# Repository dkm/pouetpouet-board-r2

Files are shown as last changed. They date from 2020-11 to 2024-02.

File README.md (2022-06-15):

# PouetPouet

The firmware is [Keyberon](https://github.com/TeXitoi/keyberon), a
pure rust firmware.

The goal was:
* build a custom keyboard from scratch
* continue to learn embedded rust
* have fun

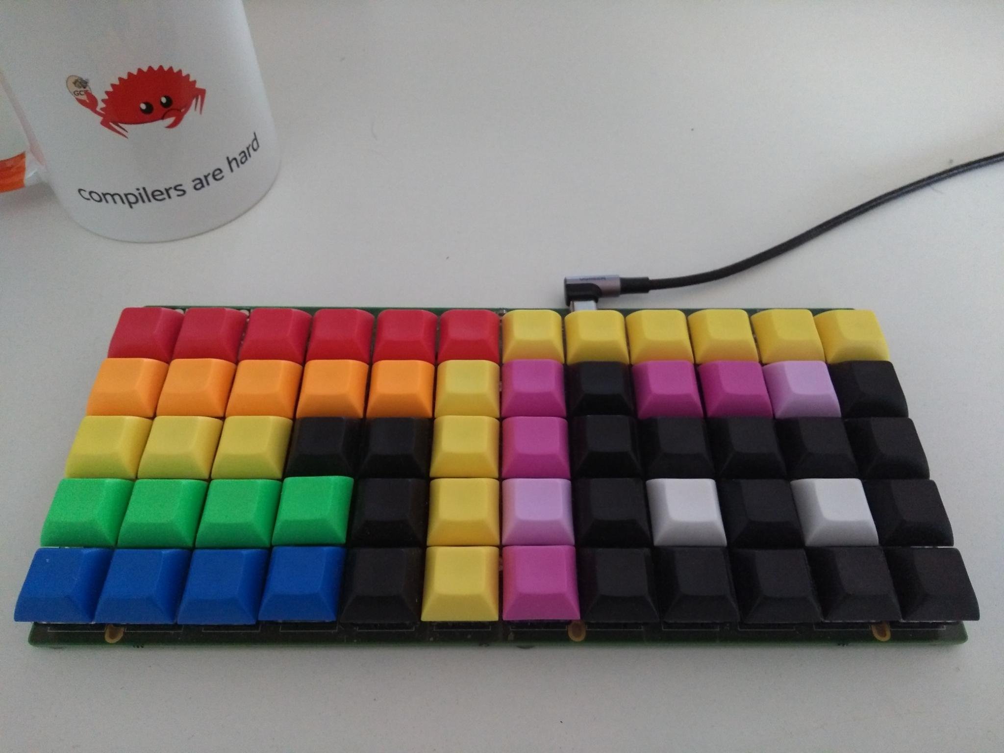
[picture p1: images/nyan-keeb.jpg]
PouetPouet Nyan

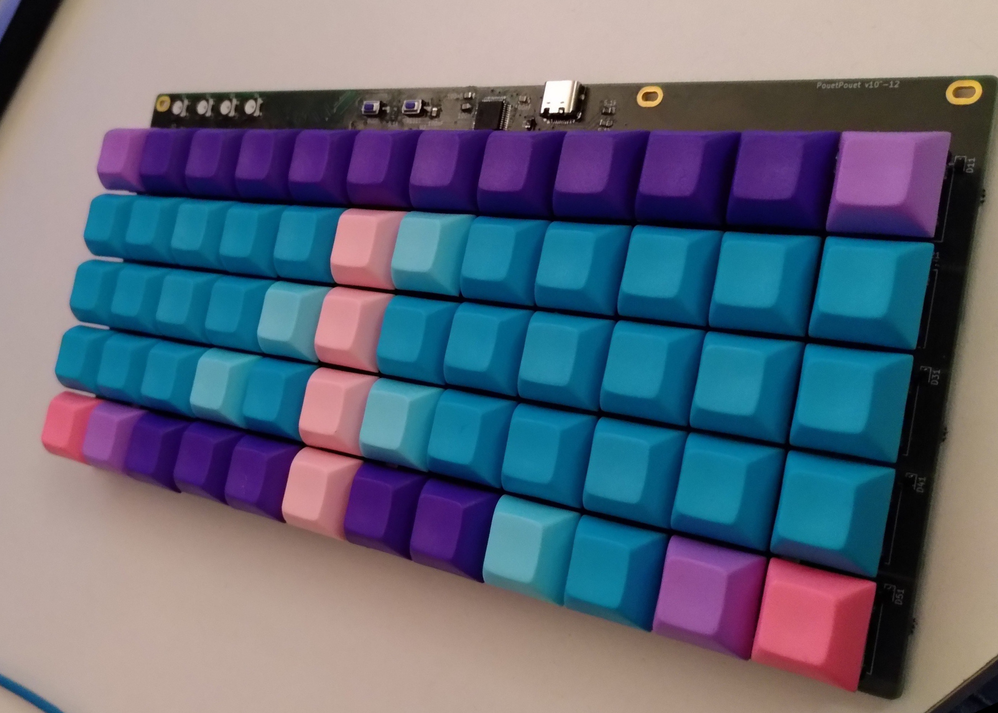
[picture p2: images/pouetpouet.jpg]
PouetPouet

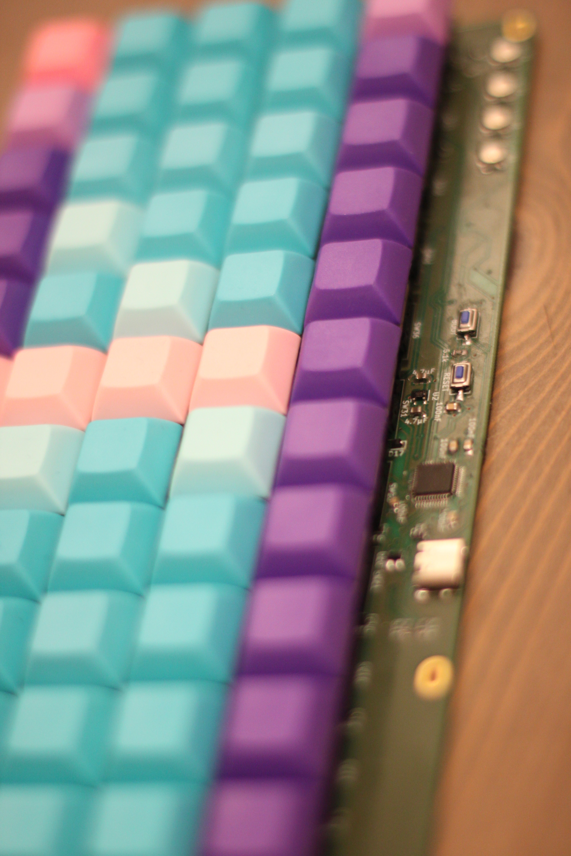
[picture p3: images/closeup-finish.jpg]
PouetPouet closeup


## Features

 * ortholinear
 * 60 keys, using Cherry MX switches, only 1U keycaps;
 * 4 RGB LEDs for status;
 * 6 RGB LEDs for backlight;
 * USB-C connector;
 * 1 STM32F072 MCU, with hardware USB DFU bootloader;
 * Only onboard SMD component (except for the switches).
 * ESD protection

## Inspiration

 * [Keyseebee](https://github.com/TeXitoi/keyseebee) for being the «I will
   change it quickly and have something ready in an hour» base project (even if
   I ended up redoing most of the hardware design). It was really nice to have a
   solid base to learn and bootstrap the project.
 * [Typematrix 2030](http://typematrix.com/2030/features.php): I own 2 of them
   and really love them. But both are getting old and some keys are not working
   correctly (this motivated the keyboard change).
 * [Steamvan](https://github.com/jmdaly/steamvan) for some KiCad design ideas;
 * [Preonic](https://olkb.com/collections/preonic) as a model: ortholinear, good
   balance between size/usability, simple.

## Usefull resources
 * [Mechanical Keyboard](https://github.com/help-14/mechanical-keyboard) is a list of DIY keyboards
 * [Awesome Mechanical Keyboard](https://github.com/BenRoe/awesome-mechanical-keyboard) is another [«awesome»](https://github.com/topics/awesome) list
 * [Masterzen](http://www.masterzen.fr/2020/05/03/designing-a-keyboard-part-1/)
   and many others for writing online tutorials for newbies like me.

## Build log

Disclaimer: I'm a software developper, this is my first real PCB design and my first try at SMD soldering: do not take anything here for granted :)

The project started as a quick-hack of Keyseebee to make it simpler but ended up
as a near full redesign. As every DIY project, the goal was to be quick and
simple (spoiler: it was neither).

Half of the parts have been soldered with a soldering iron (TS80P), the other
half with hot air station. Clearly, with my [un]existing soldering skills, the
hot air is a huge win. But I think I would have simply spent more time by only
using the iron. Even the small sod-323 diodes without the `_handsoldering` pads
(mistake) were not a real problem (tricky, but even I could do it). For
reference, I have soldered all SMD components for the second board under 2 hours
with hot air.

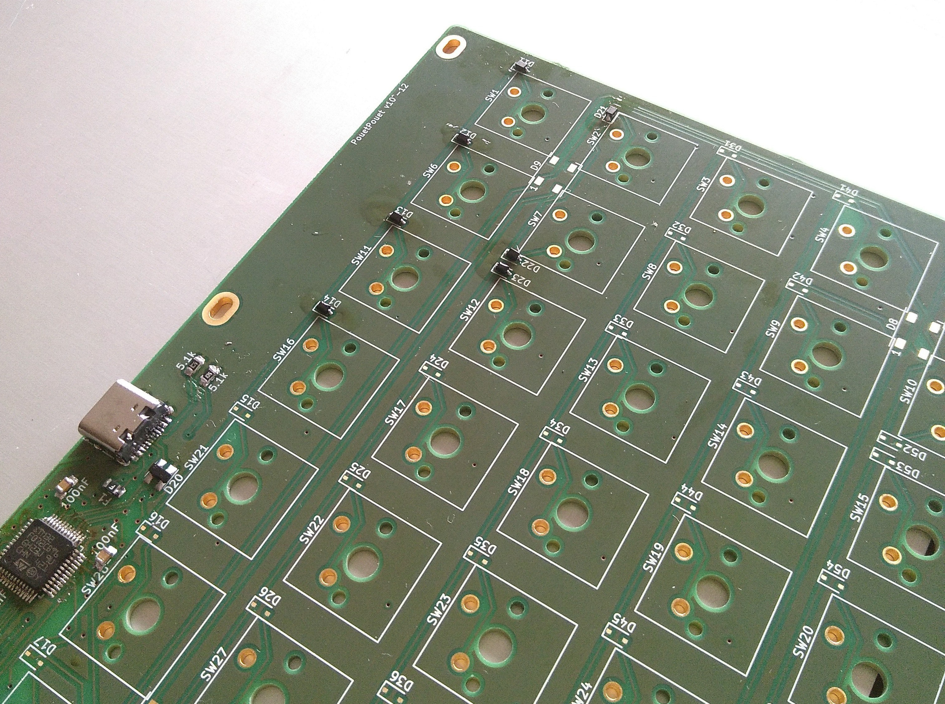
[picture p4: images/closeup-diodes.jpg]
Diodes soldering


The trickiest
part is the USB connector if you don't have a hot air station: the plastic
casing melts with the solder.

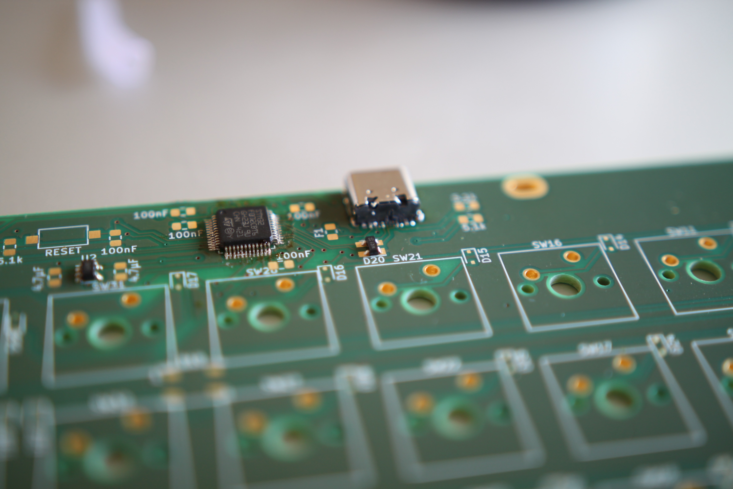
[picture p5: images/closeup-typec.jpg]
STm32 and Connector closeup


* The LEDs are mostly optional, and the 6 used for the backlight are nearly
  useless. I did not really study how to insert LEDs for a nice backlight and the
  result is not really satisfactory.
* I'll hopefully find time to use plexiglass plate to put below the PCB and
  above the visible part. I've added holes for this but never really planed
  anything really. If you really want something nice here, you may check this
  before.

## Layout

As a typematrix user, I really like the middle column with `backspace/enter/del`
so naturaly I've tried to do something similar. The [initial
layout](http://www.keyboard-layout-editor.com/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,%0A%0A%0A%0A%0A%2F%3B&_c=%23fcc0c0&a:7%3B&=%3Ci%20class%2F='mss%20mss-Unicode-BackSpace-DeleteLeft-Big-2'%3E%3C%2F%2Fi%3E&_c=%234bfad0&a:4%3B&=%3Ci%20class%2F='kb%20kb-Arrows-Top-2'%3E%3C%2F%2Fi%3E%0A%0A%0A%0A%0A%0A%0A%0A%0AC&=%2F&uarr%2F%3B%0A%0A%0A%0A%0A%0A%0A%0A%0AT&=%3Ci%20class%2F='kb%20kb-Arrows-Bottom-2'%3E%3C%2F%2Fi%3E%0A%0A%0A%0A%0A%0A%0A%0A%0AS&=4%0A%0A%0A%0A%0A%0A%0A%0A%0AR&=5%0A%0A%0A%0A%0A%0A%0A%0A%0AN&=6%0A%0A%0A%0A%0A%0A%0A%0A%0AM%3B&@=%C3%8A%0A%0A%0A%5C%0A%0A%0A%0A%0A%0A%C3%80&=%3Ci%20class%2F='fa%20fa-rotate-left'%3E%3C%2F%2Fi%3E%0A%0A%0A%7B%0A%0A%0A%0A%0A%0AY&=%3Ci%20class%2F='fa%20fa-plus'%3E%3C%2F%2Fi%3E%0A%0A%0A%7D%0A%0A%0A%0A%0A%0AX&_c=%23dbfff7%3B&=%3Ci%20class%2F='fa%20fa-minus'%3E%3C%2F%2Fi%3E%0A%0A%0A%E2%80%A6%0A%0A%0A%0A%0A%0A%2F:%0A.&_c=%234bfad0%3B&=%0A%0A%0A~%0A%0A%0A%0A%0A%0AK&_c=%23fcc0c0&a:7%3B&=%2F&crarr%2F%3B&_c=%23dbfff7&a:4%3B&=%2F&larr%2F%3B%0A%0A%0A%0A%0A%0A%0A%0A%0A%3F%0A'&_c=%234bfad0%3B&=%2F&darr%2F%3B%0A%0A%0A%0A%0A%0A%0A%0A%0AQ&=%2F&rarr%2F%3B%0A%0A%0A%0A%0A%0A%0A%0A%0AG&=1%0A%0A%0A%0A%0A%0A%0A%0A%0AH&=2%0A%0A%0A%0A%0A%0A%0A%0A%0AF&=3%0A%0A%0A%0A%0A%0A%0A%0A%0A%C3%87%3B&@_c=%23ff59d1&a:7%3B&=Ctrl&_c=%238f00ff%3B&=%2F&uArr%2F%3B&=Win&_c=%231500ff&a:4%3B&=%3Ci%20class%2F='fa%20fa-lightbulb-o'%3E%3C%2F%2Fi%3E%0A%0A%0A%0A%0A%0A%0A%0A%0AShift&_c=%238f00ff&a:7%3B&=Alt&_c=%23fcc0c0&a:4%3B&=%0A%0A%0A%2F_%0A%0A%0A%0A%0A%0Anbspc%0Aspc&_c=%238f00ff&a:7%3B&=AltGr&_c=%234bfad0&a:4%3B&=0%0A%0A%0A%0A%0A%0A%0A%0A%0AW&_c=%23dbfff7&a:5%3B&=%0A%25%0A%0A%0A%0A%0A%60&_c=%238f00ff&a:7%3B&=Del&_c=%231500ff%3B&=Shift&_c=%23ff59d1%3B&=Ctrl) has only the `%` and `w` key at different locations:
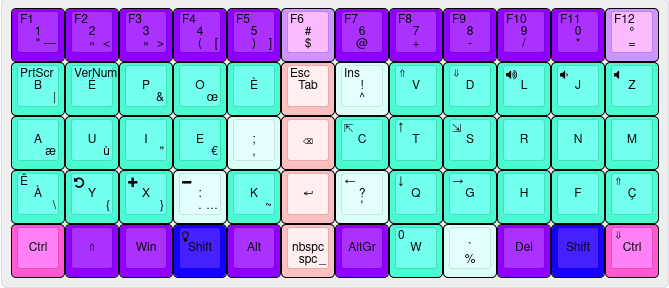
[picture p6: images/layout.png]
Typematrix-like layout


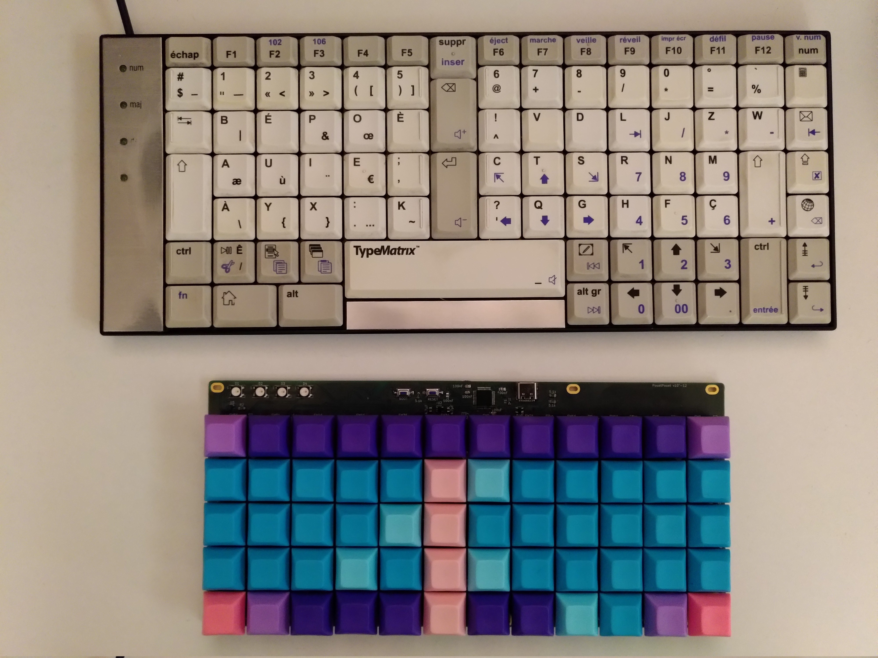
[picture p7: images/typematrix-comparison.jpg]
Typematrix comparison


You can also see how the LEDs are currently used. It's mostly useless/for fun. They may be used someday to measure typing speed or do something else, but in the meantime, they blink like this:


## Bill Of Materials

|Item |Package|Qty|Remarks |Price |
|---|---|--:|---|-----:|
| PCB | | 1 | [aisler](https://aisler.net/p/BWUOMHHS) (by 3 mini) |  28.80€  |
| 100 nF | 0805  | 5 |  aisler* | 0€ |
| PRTR5V0U2X,215 | sot-143| 1 | aisler* | 0.43€ |
| 4.7 uF | 0805  | 2 |  aisler* | 0€ |
| 470 Ohm | 0805  | 1 |  aisler* | 0€ |
| TLV70233DBVR | sot-23| 1 |  aisler* | 0.37€ |
| 74LVC1G34GW,125 | | 1 |  aisler* | 0.28€ |
| 0805L050WR (500mA Polyfuse) | 0805  | 1 |  aisler* | 1.91€ |
| RS282G05A3SMRT (micro switch) | | 2 |  aisler* | 1.26€ |
| 100nF | 0805  | 2 |  aisler* | 0€ |
| 5.1 kOhm | 0805  | 3 |  aisler* | 0€ |
| 0805L050WR (500mA Polyfuse) | 0805  | 1 |  aisler* | 0€ |
| [1N4148WS-7-F](https://fr.rs-online.com/web/p/diodes-de-commutation/7384737/) | sod-323 | 60| rs-online (by 200) | 3.24€  |
| [WS2812B](https://www.aliexpress.com/item/4000750610574.html?spm=a2g0s.9042311.0.0.27424c4dS3DGkH) | | 10| | 1€  |
| [USB TypeC HRO Receptacle](https://www.aliexpress.com/item/33056042016.html?spm=a2g0s.9042311.0.0.1d8b4c4d8WcR7j) | | 1 |  by 10 mini | 0.25€  |
| [Gateron Switch 5-pin](https://fr.aliexpress.com/item/32797603005.html?spm=a2g0s.9042311.0.0.72906c37zAMdzk) | | 60| by 65 | 15.24€ |
| [Blank DSA Keycaps](https://fr.aliexpress.com/item/32850729893.html?spm=a2g0s.9042311.0.0.3c4b6c37vkQ3vr) | | 60| by 200 | 15.6€  |
| [STM32F072CBT6](https://fr.aliexpress.com/item/4000419148272.html?spm=a2g0s.9042311.0.0.43286c37wfyZHW) | LQFP48 | 1 | | 2.87€ | 
|--------------------------------------------------------------------------|-------|--:|------------------------------------------|------|
|[TPS2553DBVR-1](https://www.digikey.fr/fr/products/detail/texas-instruments/TPS2553DBVR-1/5143873) | PKG? | 1 | FIND | ??€|
|[SK6812-Mini]() | PGK? | 60+4 | FIND | ??€ |
| 100nF | 0805  | 2 |  aisler* | 0€ |
| 9.1 kOhm | 0805  | 4 |  aisler* | 0€ |
| 68 kOhm | 0805  | 6 |  aisler* | 0€ |
|[2N7002](https://www.digikey.fr/fr/products/detail/stmicroelectronics/2N7002/654418) | SOT23-3 | 2 | FIND | ?€ |
| 100uF  | 6032 | 1 | FIND | ??€ |

The total for 3 keyboard is 71.25€. Beware that some parts can't be ordered for
the exact amount and you need to buy more (in particular, aisler won't do
anything under 3 units, so you need to spend at least ~90€ for 3 PCBs).

*: Bought using magic match from Aisler. Some components are then
 «free» (resistor, capacitor) and some are not.

## Compiling and flashing

Install the complete toolchain and utils:

```shell
curl https://sh.rustup.rs -sSf | sh
rustup target add thumbv6m-none-eabi
rustup component add llvm-tools-preview
cargo install cargo-binutils
sudo apt-get install dfu-util
```

Compile:

Do not omit the `--release` as the debug code will not fit in the memory (the
linker will raise an error).

```shell
cd firmware
cargo objcopy --bin pouetpouet --release -- -O binary pouetpouet.bin
```

To flash using dfu-util, first put the board in dfu mode by pressing
BOOT, pressing and releasing RESET and releasing BOOT. Then:

```shell
dfu-util -d 0483:df11 -a 0 -s 0x08000000:leave -D pouetpouet.bin
```

The fist time, if the write fail, your flash might be protected. To
unprotect:

```shell
dfu-util -d 0483:df11 -a 0 -s 0x08000000:force:unprotect -D pouetpouet.bin
```

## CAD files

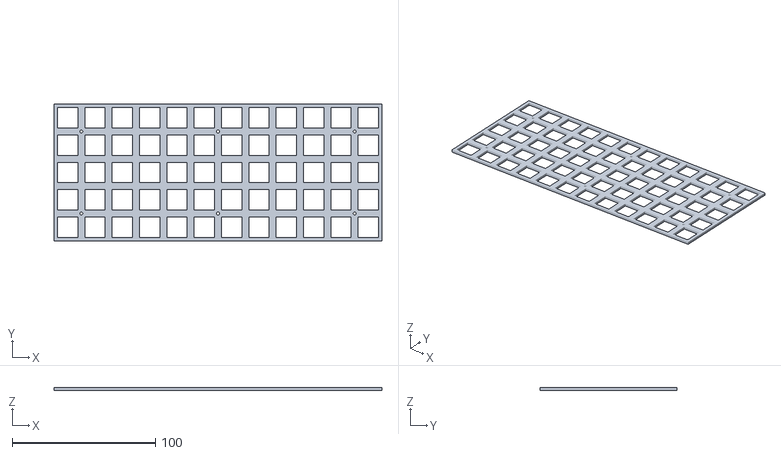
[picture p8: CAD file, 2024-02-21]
cad/plate.stl
228.6 x 95.2 x 2.00

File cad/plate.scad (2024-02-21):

// Based on keyseebee plate.scad
// https://github.com/TeXitoi/keyseebee/tree/master/cad
// Modified for https://github.com/dkm/pouetpouet-board-r2

// Configuration
// You may need to adjust, depending on the actual size of 
// your screws/standoffs and the printer/building process
// imprecision.

// by spec should be 14, can be adjusted for printer imprecision
// 14 => needs force to "click" the switch
switch_hole=14.2;

// Plate thickness
// The thicker, the stronger...
// The plate + standoff = 5mm
// With 3mm standoff, plate must be 2mm.
thickness=2;

// M2 screw outer diam between 1.9 and 2.
m2_hole=2.1;

linear_extrude(thickness)
plate();

// Corresponds to the switch footprint in KiCad.
inter_switch=19.05;

// Repeats argument on the 12*4 matrix
module key_placement() {
     for (i=[0:11]) for (j=[0:4]) translate([(i-1)*inter_switch, -(j-1)*inter_switch]) children();
}

module m2_hole_placement() {
     for (i=[0:11]) for (j=[0:4])
        if ((i==0 && j == 0)
            || (i==0 && j == 3)
            || (i==5 && j == 0)
            || (i==5 && j == 3)
            || (i==10 && j == 0)
            || (i==10 && j == 3))
        
            translate([(i-1)*inter_switch, -(j-1)*inter_switch]) children();
}

module outline() {
          hull() key_placement() square(inter_switch, center=true);
}

module plate() {
     difference() {
          outline();
          key_placement() square(switch_hole, center=true);
          m2_hole_placement() translate([inter_switch/2, -inter_switch/2]) circle(d=m2_hole, $fn=30);
     }
}

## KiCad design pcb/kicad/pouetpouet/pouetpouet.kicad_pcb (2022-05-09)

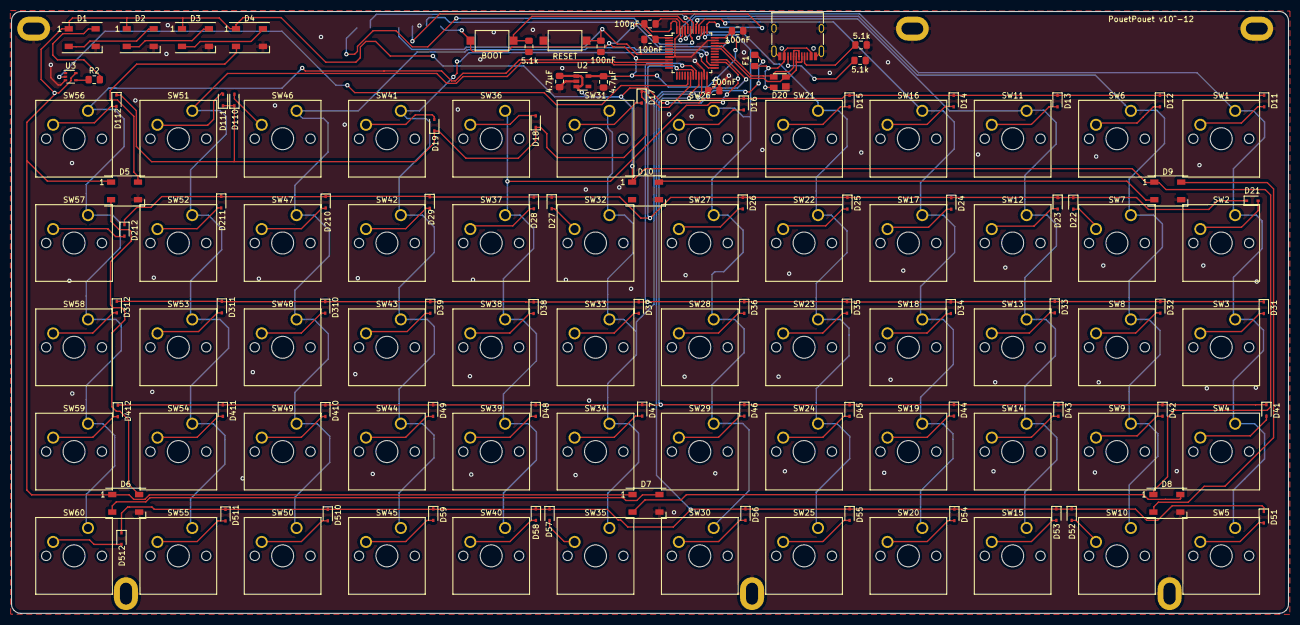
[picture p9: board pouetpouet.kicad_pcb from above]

Board: 2 copper layers, 232.6 x 109.6 mm, 156 parts (1 on the bottom side), 103 nets.

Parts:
C1, C2, C3, C4, C5: 100nF; C_0805_2012Metric_Pad1.15x1.40mm_HandSolder
C6, C7: 4.7µF; C_0805_2012Metric_Pad1.15x1.40mm_HandSolder
D1, D2, D3, D4, D5, D6, D7, D8, D9, D10: WS2812B; LED_WS2812B_PLCC4_5.0x5.0mm_P3.2mm
D11: D1.1; D_SOD-323
D12: D1.2; D_SOD-323
D13: D1.3; D_SOD-323
D14: D1.4; D_SOD-323
D15: D1.5; D_SOD-323
D16: D1.6; D_SOD-323
D17: D1.7; D_SOD-323
D18: D1.8; D_SOD-323
D19: D1.9; D_SOD-323
D20: PRTR5V0U2X; SOT-143
D21: D2.1; D_SOD-323
D22: D2.2; D_SOD-323
D23: D2.3; D_SOD-323
D24: D2.4; D_SOD-323
D25: D2.5; D_SOD-323
D26: D2.6; D_SOD-323
D27: D2.7; D_SOD-323
D28: D2.8; D_SOD-323
D29: D2.9; D_SOD-323
D31: D3.1; D_SOD-323
D32: D3.2; D_SOD-323
D33: D3.3; D_SOD-323
D34: D3.4; D_SOD-323
D35: D3.5; D_SOD-323
D36: D3.6; D_SOD-323
D37: D3.7; D_SOD-323
D38: D3.8; D_SOD-323
D39: D3.9; D_SOD-323
D41: D4.1; D_SOD-323
D42: D4.2; D_SOD-323
D43: D4.3; D_SOD-323
D44: D4.4; D_SOD-323
D45: D4.5; D_SOD-323
D46: D4.6; D_SOD-323
D47: D4.7; D_SOD-323
D48: D4.8; D_SOD-323
D49: D4.9; D_SOD-323
D51: D5.1; D_SOD-323
D52: D5.2; D_SOD-323
D53: D5.3; D_SOD-323
D54: D5.4; D_SOD-323
D55: D5.5; D_SOD-323
D56: D5.6; D_SOD-323
D57: D5.7; D_SOD-323
D58: D5.8; D_SOD-323
D59: D5.9; D_SOD-323
D110: D1.10; D_SOD-323
D111: D1.11; D_SOD-323
D112: D1.12; D_SOD-323
D210: D2.10; D_SOD-323
D211: D2.11; D_SOD-323
D212: D2.12; D_SOD-323
D310: D3.10; D_SOD-323
D311: D3.11; D_SOD-323
D312: D3.12; D_SOD-323
D410: D4.10; D_SOD-323
D411: D4.11; D_SOD-323
D412: D4.12; D_SOD-323
D510: D5.10; D_SOD-323
D511: D5.11; D_SOD-323
D512: D5.12; D_SOD-323
F1: 500mA; R_0805_2012Metric_Pad1.15x1.40mm_HandSolder
H1, H2, H3, H4, H5, H6: MountingHole_Pad; MountingHole_2.2mm_M2_Pad
J1: USB_C_Receptacle_USB2.0; USB_C_Receptacle_HRO_TYPE-C-31-M-12
J3: Conn_01x07_Male; Harwin_M20-89007xx_1x07_P2.54mm_Horizontal
R1, R6, R7: 5.1k; R_0805_2012Metric_Pad1.15x1.40mm_HandSolder
R2: 470; R_0805_2012Metric_Pad1.15x1.40mm_HandSolder
SW1, SW2, SW3, SW4, SW5, SW6, SW7, SW8, SW9, SW10, SW11, SW12, SW13, SW14, SW15, SW16, SW17, SW18, SW19, SW20, SW21, SW22, SW23, SW24, SW25, SW26, SW27, SW28, SW29, SW30, SW31, SW32, SW33, SW34, SW35, SW36, SW37, SW38, SW39, SW40, SW41, SW42, SW43, SW44, SW45, SW46, SW47, SW48, SW49, SW50, SW51, SW52, SW53, SW54, SW55, SW56, SW57, SW58, SW59, SW60: SW_Push; SW_Cherry_MX_1.00u_PCB
SWBOOT1: BOOT; SW_SPST_CK_RS282G05A3
SWRST1: RESET; SW_SPST_CK_RS282G05A3
U1: STM32; LQFP-48_7x7mm_P0.5mm
U2: TLV70233_SOT23-5; SOT-23-5
U3: 74LVC1G34; SOT-353_SC-70-5

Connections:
+3V3: C2.2, C3.2, C4.2, C5.2, C6.2, J3.1, SWBOOT1.2, U1.1, U1.9, U1.24, U1.36, U1.48, U2.5
+5V: C7.2, D1.1, D2.1, D3.1, D4.1, D5.1, D6.1, D7.1, D8.1, D9.1, D10.1, F1.2, U2.1, U2.3, U3.5
COL1: SW1.1, SW2.1, SW3.1, SW4.1, SW5.1, U1.46
COL2: SW6.1, SW7.1, SW8.1, SW9.1, SW10.1, U1.45
COL3: SW11.1, SW12.1, SW13.1, SW14.1, SW15.1, U1.41
COL4: SW16.1, SW17.1, SW18.1, SW19.1, SW20.1, U1.40
COL5: SW21.1, SW22.1, SW23.1, SW24.1, SW25.1, U1.39
COL6: SW26.1, SW27.1, SW28.1, SW29.1, SW30.1, U1.38
COL7: SW31.1, SW32.1, SW33.1, SW34.1, SW35.1, U1.28
COL8: SW36.1, SW37.1, SW38.1, SW39.1, SW40.1, U1.27
COL9: SW41.1, SW42.1, SW43.1, SW44.1, SW45.1, U1.25
COL10: SW46.1, SW47.1, SW48.1, SW49.1, SW50.1, U1.26
COL11: SW51.1, SW52.1, SW53.1, SW54.1, SW55.1, U1.11
COL12: SW56.1, SW57.1, SW58.1, SW59.1, SW60.1, U1.10
D+: D20.3, J1.A6, J1.B6, U1.33
D-: D20.2, J1.A7, J1.B7, U1.32
GND: C1.1, C2.1, C3.1, C4.1, C5.1, C6.1, C7.1, D1.3, D2.3, D3.3, D4.3, D5.3, D6.3, D7.3, D8.3, D9.3, D10.3, D20.1, H1.1, H2.1, H3.1, H4.1, H5.1, H6.1, J1.A1, J1.A12, J1.B1, J1.B12, J1.S1, J3.5, R1.2, R6.2, R7.2, SWRST1.1, U1.8, U1.23, U1.35, U1.47, U2.2, U3.3
NRST: C1.2, J3.4, SWRST1.2, U1.7
unnamed: D1.2, D2.4
unnamed: D1.4, R2.2
unnamed: D2.2, D3.4
unnamed: D3.2, D4.4
unnamed: D4.2, D5.4
unnamed: D5.2, D6.4
unnamed: D6.2, D7.4
unnamed: D7.2, D8.4
unnamed: D8.2, D9.4
unnamed: D9.2, D10.4
unnamed: D11.2, SW1.2
unnamed: D12.2, SW6.2
unnamed: D13.2, SW11.2
unnamed: D14.2, SW16.2
unnamed: D15.2, SW21.2
unnamed: D16.2, SW26.2
unnamed: D17.2, SW31.2
unnamed: D18.2, SW36.2
unnamed: D19.2, SW41.2
unnamed: D21.2, SW2.2
unnamed: D22.2, SW7.2
unnamed: D23.2, SW12.2
unnamed: D24.2, SW17.2
unnamed: D25.2, SW22.2
unnamed: D26.2, SW27.2
unnamed: D27.2, SW32.2
unnamed: D28.2, SW37.2
unnamed: D29.2, SW42.2
unnamed: D31.2, SW3.2
unnamed: D32.2, SW8.2
unnamed: D33.2, SW13.2
unnamed: D34.2, SW18.2
unnamed: D35.2, SW23.2
unnamed: D36.2, SW28.2
unnamed: D37.2, SW33.2
unnamed: D38.2, SW38.2
unnamed: D39.2, SW43.2
unnamed: D41.2, SW4.2
unnamed: D42.2, SW9.2
unnamed: D43.2, SW14.2
unnamed: D44.2, SW19.2
unnamed: D45.2, SW24.2
unnamed: D46.2, SW29.2
unnamed: D47.2, SW34.2
unnamed: D48.2, SW39.2
unnamed: D49.2, SW44.2
unnamed: D51.2, SW5.2
unnamed: D52.2, SW10.2
unnamed: D53.2, SW15.2
unnamed: D54.2, SW20.2
unnamed: D55.2, SW25.2
unnamed: D56.2, SW30.2
unnamed: D57.2, SW35.2
unnamed: D58.2, SW40.2
unnamed: D59.2, SW45.2
unnamed: D110.2, SW46.2
unnamed: D111.2, SW51.2
unnamed: D112.2, SW56.2
unnamed: D210.2, SW47.2
unnamed: D211.2, SW52.2
unnamed: D212.2, SW57.2
unnamed: D310.2, SW48.2
unnamed: D311.2, SW53.2
unnamed: D312.2, SW58.2
unnamed: D410.2, SW49.2
unnamed: D411.2, SW54.2
unnamed: D412.2, SW59.2
unnamed: D510.2, SW50.2
unnamed: D511.2, SW55.2
unnamed: D512.2, SW60.2
unnamed: J1.A5, R7.1
unnamed: J1.B5, R6.1
unnamed: R1.1, SWBOOT1.1, U1.44
unnamed: R2.1, U3.4
ROW1: D11.1, D12.1, D13.1, D14.1, D15.1, D16.1, D17.1, D18.1, D19.1, D110.1, D111.1, D112.1, U1.18
ROW2: D21.1, D22.1, D23.1, D24.1, D25.1, D26.1, D27.1, D28.1, D29.1, D210.1, D211.1, D212.1, U1.19
ROW3: D31.1, D32.1, D33.1, D34.1, D35.1, D36.1, D37.1, D38.1, D39.1, D310.1, D311.1, D312.1, U1.20
ROW4: D41.1, D42.1, D43.1, D44.1, D45.1, D46.1, D47.1, D48.1, D49.1, D410.1, D411.1, D412.1, U1.21
ROW5: D51.1, D52.1, D53.1, D54.1, D55.1, D56.1, D57.1, D58.1, D59.1, D510.1, D511.1, D512.1, U1.22
SPI1_MOSI_PA7: U1.17, U3.2
SWDCLK: J3.3, U1.37
SWDIO: J3.2, U1.34
U1_RX_PB7: J3.7, U1.43
U1_TX_PB6: J3.6, U1.42
VCC: D20.4, F1.1, J1.A4, J1.A9, J1.B4, J1.B9

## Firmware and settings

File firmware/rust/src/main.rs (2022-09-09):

#![no_main]
#![no_std]

// set the panic handler
use panic_halt as _;

use core::convert::Infallible;
use keyberon::action::{k, l, Action::*, HoldTapConfig};
use keyberon::key_code::KeyCode::*;
use keyberon::layout::{Event, Layout};

use keyberon::matrix::Matrix;
use rtic::app;
use stm32f0xx_hal as hal;
use usb_device::bus::UsbBusAllocator;
use usb_device::class::UsbClass as _;
use usb_device::device::UsbDeviceState;

extern crate smart_leds;
extern crate ws2812_spi;
use smart_leds::{brightness, colors, SmartLedsWrite, RGB8};

use ws2812_spi as ws2812;

use hal::delay::Delay;
use hal::gpio::{gpioa, Alternate, Input, Output, Pin, PullUp, PushPull, AF0};
use hal::prelude::*;

mod layout;
use layout::CustomActions;

use embedded_hal::spi::FullDuplex;

use hal::usb;
use hal::{
    spi::{EightBit, Mode, Phase, Polarity},
    stm32, timers,
};

use keyberon::debounce::Debouncer;
use keyberon::key_code::KbHidReport;

type Spi = hal::spi::Spi<
    stm32::SPI1,
    gpioa::PA5<Alternate<AF0>>,
    gpioa::PA6<Alternate<AF0>>,
    gpioa::PA7<Alternate<AF0>>,
    EightBit,
>;

type UsbClass = keyberon::Class<'static, usb::UsbBusType, Leds<Spi>>;

type UsbDevice = usb_device::device::UsbDevice<'static, usb::UsbBusType>;

trait ResultExt<T> {
    fn get(self) -> T;
}
impl<T> ResultExt<T> for Result<T, Infallible> {
    fn get(self) -> T {
        match self {
            Ok(v) => v,
            Err(e) => match e {},
        }
    }
}

pub const NUM_LEDS: u8 = 4+12*5;
pub struct Leds<SPI> {
    ws: ws2812::Ws2812<SPI>,
    leds: [RGB8; NUM_LEDS as usize],
}

impl<SPI, E> Leds<SPI>
    where
        SPI: FullDuplex<u8, Error = E>,
{
    fn set_key_led(&mut self, line: u8, col: u8, status: bool, backlight: &Backlight) {

        //  ,- 3, 2, 1, 0] <- Array LEDs starts on status, from the right.
        //  |
        //  `----------------------------------------------------,
        //                                                       |
        //  ,-- 15, 14, 13, 12, 11, 10,  9,  8,  7,  6,  5,  4, <'  line 0
        //  |
        //  `-> 16, 17, 18, 19, 20, 21, 22, 23, 24, 25, 26, 27,...  line 1
        //
        //  col: 0   1   2   3   4   5   6   7   8   9  10  11

        let coord = (4 + (line * 12) + (if line%2 != 0 {11-col} else {col})) as usize;

        if status {
            self.leds[coord] = backlight.key_color;
        } else {
            self.leds[coord] = colors::BLACK;
        }
    }

    fn refresh(&mut self, backlight: &Backlight) {
        if self.ws.write(brightness(self.leds.iter().cloned(), backlight.key_brightness)).is_err() {
            panic!();
        }
    }
}

impl<SPI, E> keyberon::keyboard::Leds for Leds<SPI>
where
    SPI: FullDuplex<u8, Error = E>,
{
    fn caps_lock(&mut self, status: bool) {
        if status {
            self.leds[0] = colors::BLUE;
        } else {
            self.leds[0] = colors::BLACK;
        }
        if self.ws.write(brightness(self.leds.iter().cloned(), NUM_LEDS)).is_err() {
            panic!();
        }
    }

    fn num_lock(&mut self, status: bool) {
        if status {
            self.leds[1] = colors::GREEN;
        } else {
            self.leds[1] = colors::BLACK;
        }
        if self.ws.write(brightness(self.leds.iter().cloned(), NUM_LEDS)).is_err() {
            panic!();
        }
    }

    fn compose(&mut self, status: bool) {
        if status {
            self.leds[3] = colors::VIOLET;
        } else {
            self.leds[3] = colors::BLACK;
        }
        if self.ws.write(brightness(self.leds.iter().cloned(), NUM_LEDS)).is_err() {
            panic!();
        }

    }
}

#[derive(Debug, Clone, Copy, Eq, PartialEq)]
pub enum BacklightMode {
    Off,
    Solid(RGB8),
    Circling(RGB8, usize, usize, usize, bool),
    Breath(RGB8, usize, usize, bool),
}

pub struct Backlight {
    mode: BacklightMode,
    brightness: u8,

    key_color : RGB8,
    key_brightness: u8,
}

trait ColorSeq {
    fn next_color(&self) -> RGB8;
}

const COLORS_SEQ: [RGB8; 5] = [
    colors::RED,
    colors::GREEN,
    colors::BLUE,
    colors::VIOLET,
    colors::YELLOW,
];

impl ColorSeq for RGB8 {
    fn next_color(&self) -> RGB8 {
        let mut next = false;

        for c in &COLORS_SEQ {
            if next {
                return *c;
            }

            if *self == *c {
                next = true;
            }
        }

        COLORS_SEQ[0]
    }
}

impl Backlight {
    pub fn next_mode(&mut self) {
        self.mode = match self.mode {
            BacklightMode::Off => BacklightMode::Solid(colors::RED),
            BacklightMode::Solid(_) => BacklightMode::Circling(colors::RED, 100, 0, 0, true),
            BacklightMode::Circling(_, _, _, _, _) => {
                BacklightMode::Breath(colors::RED, 10, 0, true)
            }
            BacklightMode::Breath(_, _, _, _) => BacklightMode::Off,
        }
    }

    pub fn change_freq(&mut self, up: bool) {
        self.mode = match self.mode {
            BacklightMode::Breath(c, tstep, step, dir) => {
                let tstep = if up {
                    if tstep - 10 > 10 {
                        tstep - 10
                    } else {
                        10
                    }
                } else if tstep + 10 < 1000 {
                    tstep + 10
                } else {
                    1000
                };
                BacklightMode::Breath(c, tstep, step, dir)
            }
            BacklightMode::Circling(c, tstep, step, i, dir) => {
                let tstep = if up {
                    if tstep - 10 > 10 {
                        tstep - 10
                    } else {
                        10
                    }
                } else if tstep + 10 < 1000 {
                    tstep + 10
                } else {
                    1000
                };
                BacklightMode::Circling(c, tstep, step, i, dir)
            }
            any => any,
        }
    }

    pub fn next_color(&mut self) {
        self.mode = match self.mode {
            BacklightMode::Solid(c) => BacklightMode::Solid(c.next_color()),
            BacklightMode::Breath(c, tstep, step, dir) => {
                BacklightMode::Breath(c.next_color(), tstep, step, dir)
            }
            BacklightMode::Circling(c, ts, s, i, dir) => {
                BacklightMode::Circling(c.next_color(), ts, s, i, dir)
            }
            any => any,
        }
    }

    pub fn refresh_leds(&mut self, leds: &mut Leds<Spi>) {
        self.mode = match self.mode {
            BacklightMode::Off => {
                for l in leds.leds[4..].iter_mut() {
                    *l = colors::BLACK;
                }
                BacklightMode::Off
            }

            BacklightMode::Solid(c) => {
                for l in leds.leds[4..].iter_mut() {
                    *l = c;
                }
                BacklightMode::Solid(c)
            }

            BacklightMode::Breath(c, tstep, step, dir) => {
                let mut step = step + 1;
                let mut new_dir = dir;

                if step >= tstep {
                    step = 0;

                    for l in leds.leds[4..].iter_mut() {
                        *l = c;
                    }

                    if dir {
                        if self.brightness == 100 {
                            self.brightness -= 1;
                            new_dir = false;
                        }
                        self.brightness += 1;
                    } else {
                        if self.brightness == 5 {
                            self.brightness += 1;
                            new_dir = true;
                        }
                        self.brightness -= 1;
                    }
                }

                BacklightMode::Breath(c, tstep, step, new_dir)
            }

            BacklightMode::Circling(c, tstep, step, index, dir) => {
                let mut new_dir = dir;
                let mut new_index = index;

                let mut step = step + 1;

                if step >= tstep {
                    step = 0;

                    if new_index == 0 && !dir {
                        new_index = 0;
                        new_dir = true;
                    } else if new_index == 6 && dir {
                        new_index = 6;
                        new_dir = false;
                    } else {
                        new_index = if dir { index + 1 } else { index - 1 };
                    }
                }

                for (i, l) in leds.leds[4..].iter_mut().enumerate() {
                    let ni = if new_index == 0 { 5 } else { new_index - 1 };
                    if i == ni {
                        *l = c;
                    } else {
                        *l = colors::BLACK;
                    }
                }
                BacklightMode::Circling(c, tstep, step, new_index as usize, new_dir)
            }
        };

        if leds.ws
            .write(brightness(leds.leds.iter().cloned(), self.brightness)).is_err() {
                panic!();
            }
    }
}


#[app(device = crate::hal::pac, peripherals = true, dispatchers = [CEC_CAN, SPI2])]
mod app {
    use super::*;

    #[shared]
    struct Shared {
        usb_dev: UsbDevice,
        usb_class: UsbClass,

        #[lock_free]
        layout: Layout<12, 5, 2, CustomActions>,

        #[lock_free]
        backlight: Backlight,
    }

    #[local]
    struct Local {
        matrix: Matrix<Pin<Input<PullUp>>, Pin<Output<PushPull>>, 12, 5>,
        debouncer: Debouncer<[[bool; 12]; 5]>,
        timer: timers::Timer<stm32::TIM3>,
    }

    #[init(local = [bus: Option<UsbBusAllocator<usb::UsbBusType>> = None])]
    fn init(mut c: init::Context) -> (Shared, Local, init::Monotonics) {

        let mut rcc = c
            .device
            .RCC
            .configure()
            .hsi48()
            .enable_crs(c.device.CRS)
            .sysclk(48.mhz())
            .pclk(24.mhz())
            .freeze(&mut c.device.FLASH);

        let gpioa = c.device.GPIOA.split(&mut rcc);
        let gpiob = c.device.GPIOB.split(&mut rcc);

        let usb = usb::Peripheral {
            usb: c.device.USB,
            pin_dm: gpioa.pa11,
            pin_dp: gpioa.pa12,
        };

        *c.local.bus = Some(usb::UsbBusType::new(usb));
        let usb_bus = c.local.bus.as_ref().unwrap();

        // Handling of ws2812 leds

        let pa5 = gpioa.pa5; // sck
        let pa6 = gpioa.pa6; // miso
        let pa7 = gpioa.pa7; // mosi

        // Configure pins for SPI
        let (sck, miso, mosi) = cortex_m::interrupt::free(move |cs| {
            (
                pa5.into_alternate_af0(cs),
                pa6.into_alternate_af0(cs),
                pa7.into_alternate_af0(cs),
            )
        });

        const MODE: Mode = Mode {
            polarity: Polarity::IdleHigh,
            phase: Phase::CaptureOnSecondTransition,
        };
        let spi = Spi::spi1(
            c.device.SPI1,
            (sck, miso, mosi),
            MODE,
            3_000_000.hz(),
            &mut rcc,
        );

        // ws2812
        let mut ws = ws2812::Ws2812::new(spi);

        // Do a simple smooth blink at start
        let mut delay = Delay::new(c.core.SYST, &rcc);
        let tmpleds = [colors::GREEN; NUM_LEDS as usize];
        for i in (0..100).chain((0..100).rev()) {
            ws.write(brightness(tmpleds.iter().cloned(), i)).unwrap();
            delay.delay_ms(5u8);
        }

        let mut leds = Leds {
            ws,
            leds: [colors::BLACK; NUM_LEDS as usize],
        };

        leds.ws.write(leds.leds.iter().cloned()).unwrap();

        let usb_class = keyberon::new_class(usb_bus, leds);
        let usb_dev = keyberon::new_device(usb_bus);

        let mut timer = timers::Timer::tim3(c.device.TIM3, 1.khz(), &mut rcc);
        timer.listen(timers::Event::TimeOut);

        let pa0 = gpioa.pa0;
        let pa10 = gpioa.pa10;
        let pa15 = gpioa.pa15;

        let matrix = cortex_m::interrupt::free(move |cs| {
            Matrix::new(
                [
                    pa0.into_pull_up_input(cs).downgrade(),
                    gpiob.pb12.into_pull_up_input(cs).downgrade(),
                    gpiob.pb13.into_pull_up_input(cs).downgrade(),
                    gpiob.pb14.into_pull_up_input(cs).downgrade(),
                    gpiob.pb15.into_pull_up_input(cs).downgrade(),
                    pa10.into_pull_up_input(cs).downgrade(),
                    pa15.into_pull_up_input(cs).downgrade(),
                    gpiob.pb3.into_pull_up_input(cs).downgrade(),
                    gpiob.pb4.into_pull_up_input(cs).downgrade(),
                    gpiob.pb5.into_pull_up_input(cs).downgrade(),
                    gpiob.pb8.into_pull_up_input(cs).downgrade(),
                    gpiob.pb9.into_pull_up_input(cs).downgrade(),
                ],
                [
                    gpiob.pb0.into_push_pull_output(cs).downgrade(),
                    gpiob.pb1.into_push_pull_output(cs).downgrade(),
                    gpiob.pb2.into_push_pull_output(cs).downgrade(),
                    gpiob.pb10.into_push_pull_output(cs).downgrade(),
                    gpiob.pb11.into_push_pull_output(cs).downgrade(),

                ],
            )});

        (
            Shared {
                usb_dev,
                usb_class,
                layout: Layout::new(&crate::layout::LAYERS),
                backlight: Backlight {
                    mode: BacklightMode::Off,
                    brightness: 8,

                    key_color: colors::BLUE,
                    key_brightness: 50,
                },
            },

            Local {
                timer,
                debouncer: Debouncer::new([[false; 12]; 5], [[false; 12]; 5], 5),
                matrix: matrix.get(),
            },
            init::Monotonics(),
        )
    }

    #[task(binds = USB, priority = 3, shared = [usb_dev, usb_class])]
    fn usb_rx(c: usb_rx::Context) {
        (c.shared.usb_dev, c.shared.usb_class).lock(|usb_dev, usb_class| {
            if usb_dev.poll(&mut [usb_class]) {
                usb_class.poll();
            }
        });
    }


    #[task(priority = 1, shared = [usb_class, backlight])]
    fn handle_custom_action (mut c: handle_custom_action::Context, tick: keyberon::layout::CustomEvent<CustomActions>) {
        // This does not work
        panic!();

        let b = c.shared.backlight;

        c.shared.usb_class.lock(|u|{
            match tick {
                keyberon::layout::CustomEvent::Release(CustomActions::LightUp) => {
                    let bl_val = &mut b.brightness;
                    *bl_val = if *bl_val == 100 { 100 } else { *bl_val + 1 };

                    let leds = u.device_mut().leds_mut();
                    if leds.ws
                        .write(brightness(leds.leds.iter().cloned(), *bl_val)).is_err() {
                            panic!();
                        }

                }
                keyberon::layout::CustomEvent::Release(CustomActions::LightDown) => {
                    let bl_val = &mut b.brightness;
                    *bl_val = if *bl_val == 0 { 0 } else { *bl_val - 1 };

                    let leds = u.device_mut().leds_mut();
                    if leds.ws
                        .write(brightness(leds.leds.iter().cloned(), *bl_val)).is_err() {
                            panic!();
                        }
                }
                keyberon::layout::CustomEvent::Release(CustomActions::ColorCycle) => {
                    b.next_color();
                }
                keyberon::layout::CustomEvent::Release(CustomActions::ModeCycle) => {
                    b.next_mode();
                }
                keyberon::layout::CustomEvent::Release(CustomActions::FreqUp) => {
                    b.change_freq(true);
                }
                keyberon::layout::CustomEvent::Release(CustomActions::FreqDown) => {
                    b.change_freq(false);
                }
                _ => (),
            }
        });
    }

    #[task(priority = 2, shared = [usb_dev, usb_class, layout])]
    fn tick_keyberon(mut c: tick_keyberon::Context) {
        let tick = c.shared.layout.tick();

        if c.shared.usb_dev.lock(|d| d.state()) != UsbDeviceState::Configured {
            return;
        }

        // This does not work. Need to redesign LED sharing and avoid
        // low-prio task access to usb_class.

        // handle_custom_action::spawn(tick).unwrap();

        let report: KbHidReport = c.shared.layout.keycodes().collect();
        if !c.shared.usb_class
            .lock(|k| k.device_mut().set_keyboard_report(report.clone()))
        {
            return;
        }
        while let Ok(0) = c.shared.usb_class.lock(|k| k.write(report.as_bytes())) {}
    }

    #[task(priority = 2, capacity = 8, shared = [layout])]
    fn handle_event(c: handle_event::Context, event: Event) {
        c.shared.layout.event(event)
    }

    #[task(priority = 1, capacity = 16, shared = [usb_class, backlight])]
    fn handle_led_matrix(mut c: handle_led_matrix::Context, event: Event) {

        let backlight = c.shared.backlight;
        c.shared.usb_class.lock(|k| {
            let leds = k.device_mut().leds_mut();
            match event {
                Event::Press(line, col) => leds.set_key_led(line, col, true, backlight),
                Event::Release(line, col) => leds.set_key_led(line, col, false, backlight),
            }
        });
    }

    #[task(priority = 1, capacity = 8, shared = [usb_class, backlight])]
    fn refresh_led_matrix(mut c: refresh_led_matrix::Context) {

        let backlight = c.shared.backlight;
        c.shared.usb_class.lock(|k| {
            let leds = k.device_mut().leds_mut();
            leds.refresh(backlight);
        });
    }

    #[task(
        binds = TIM3,
        priority = 1,
        local = [matrix, debouncer, timer],
    )]
    fn tick(c: tick::Context) {
        c.local.timer.wait().ok();

        for event in c
            .local
            .debouncer
            .events(c.local.matrix.get().get())
        {
            // Better would be to reset all LEDs on error to avoid any strange
            // setup.

            handle_led_matrix::spawn(event).unwrap_or_default();
            handle_event::spawn(event).unwrap();
        }

        // will be refresh when slot available
        refresh_led_matrix::spawn().unwrap_or_default();

        tick_keyberon::spawn().unwrap();
    }
}

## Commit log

2020-11-11 Initial work for Pouetpouet board
    Based on keyseebee but now very different.
    [bac.light.sch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]
2020-11-11 Update BOM with correct parts, vendor and price.
2020-11-11 Modified the bépo layout a bit
    Moved few keys around:
    - swapped w and AltGr.
    - swapped Raise and Shift
    - added ê/Ê
    [main.rs]
2020-12-17 Update code after keyberon update
    Simply port current firmware. No CustomAction yet.
2021-01-10 Simple backlight support using custom actions.
    Use keyberon's custom action to create some useless LEDs mode.
    Frequency (when applicable) and color can be changed by some keypress.
2021-01-12 Add sample gif for showing LEDs, refresh layout
    Update layout with latest changes (and add LEDs control keys).
2021-01-15 Add a simple LED bleep at start
    Always friendly to have a feedback from the device after it has booted.
2021-01-16 Change Keyboard::leds to leds_mut following upstream change.
    The function changed names while upstreaming it.
    Reverting back keyberon to upstream git instead following this change.
    [main.rs]
2021-05-19 Use new macro to define layers + cleaning
    Use the new layout!() macro for easier and more readable layers definitions.
    Add a testmode feature, used to have 'a' on all keys, easier to test if all
    switch are correctly working or not.
    Also fixed some minor warnings.
    [main.rs]
2021-05-20 Add simple CAD file for plate
    Initial plate design for early test/prototype.
    [plate.scad, plate.stl]
2022-05-09 update kicad footprints repos
2022-05-09 Update to KiCad 6.0
    Simply open and save the SCH and PCB to convert them to KiCad 6.0.
    No checks done on the result.
    [bac.light.kicad_sch, pouetpouet.kicad_pcb, pouetpouet.kicad_sch]
2022-06-15 New revision for PouetPouet board
    What is changing:
    - Cherry-MX hotswap sockets for all 60 switches
    - Per switch RGB LED (SK6812-MiniE)
    What is not changing:
    - Size (exact same board cutout)
    - overall components (mcu stmf072)
    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
    [bac.light.kicad_sch, pouetpouet.kicad_sch]
2022-07-22 Rev 2.1 for error with sk6812mini-e
    The symbol used for the mini-e is the mini one. Pins numbering for both parts
    are NOT the same: leads to non functionnal keys backlight.
    This changes:
    - fixes this error
    - make the OSHW logo nicer (copper instead of silk)
    The symbol used for mini-e comes from the Djinn keyboard.
    [bac.light.kicad_sch, pouetpouet.kicad_sch]
2022-07-22 rust: Initial hold tap work
    Currently not working (Tap action is never triggered unless some other
    keys is tapped simultaneous).
    [main.rs]
2022-07-22 Update all crate, in particular rtic
    Keyboard works, but customevents for leds are not working (yet).
    [main.rs]
2022-07-22 Update GPIO for rev2 board
2022-07-27 pcb: minor tuning of GND plane
    Tune GND plane + moved minor tracks.
2022-07-30 pcb: apply rules, fix last warning
    Add more PWR track for one led
    RC for 2.1
2022-08-28 ada: modifiers, layers and regular keys are working
    Still need to add timings as currently the processor is looping full speed,
    which may cause some lost events as the USB only polls at the frequency
    advertised in the descriptor (few ms).
2022-08-28 ada: initial support for timing
    Use clock configuration (only HSE48 for now) and use timer to have a 1ms update
    frequency.
2022-08-28 ada: build stm32 hal in dev mode
    In release mode the mcu crashes very quickly, there must be some UB somewhere...
2022-09-08 rust: initial support for keys LED matrix
    LEDs are set/clear for press/release events.
2022-09-09 rust: try to use custom event to change color
    TLDR; needs a redesign for correctly sharing LEDS (in usb_class) and lower prio
    data in `backlight`.
    [main.rs]
2023-10-26 cad: adjust plate
    Fix the switch size from 19 to 19.05 to match actual footprint.
    [plate.scad]
2024-01-24 cad: wip on plate
    Add screw holes.
    [plate.scad, plate.stl]
2024-01-25 cad: adjust M2 screw holes
    [plate.scad, plate.stl]
2024-02-09 cad: adjust M2 holes in plate
    Previous holes were a bit too large after printing: standoffs are a
    bit smaller and fall through the plate.
    [plate.scad, plate.stl]
2024-02-17 cad: adjust (again) plate holes size
    Previous adjustements were not enough, standoff are still too thin.
    Enlarge a bit switch holes to avoid having to force the switches in.
    [plate.scad, plate.stl]
2024-02-21 cad: fix M2 hole
    By default, circle() takes the radius, not the diameter. No surprises
    the holes were too large.
    [plate.scad, plate.stl]
